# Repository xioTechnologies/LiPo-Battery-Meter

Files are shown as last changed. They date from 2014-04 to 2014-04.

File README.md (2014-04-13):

LiPo-Battery-Meter
==================

Battery meter for single cell [LiPo batteries](https://www.sparkfun.com/products/339) to display a battery voltage between 2.8 V to 4.2 V as an LED bar graph.  Uses the [LM3914](https://www.sparkfun.com/products/12694).  The PCB has foot prints compatible with either ten 1206 LEDs or a [single LED bar graph package](https://www.sparkfun.com/products/9935).  Inspired by [Dave Jone's tutorial](http://www.eevblog.com/2011/09/29/eevblog-204-designing-a-li-ion-battery-gauge-with-the-lm3914/).

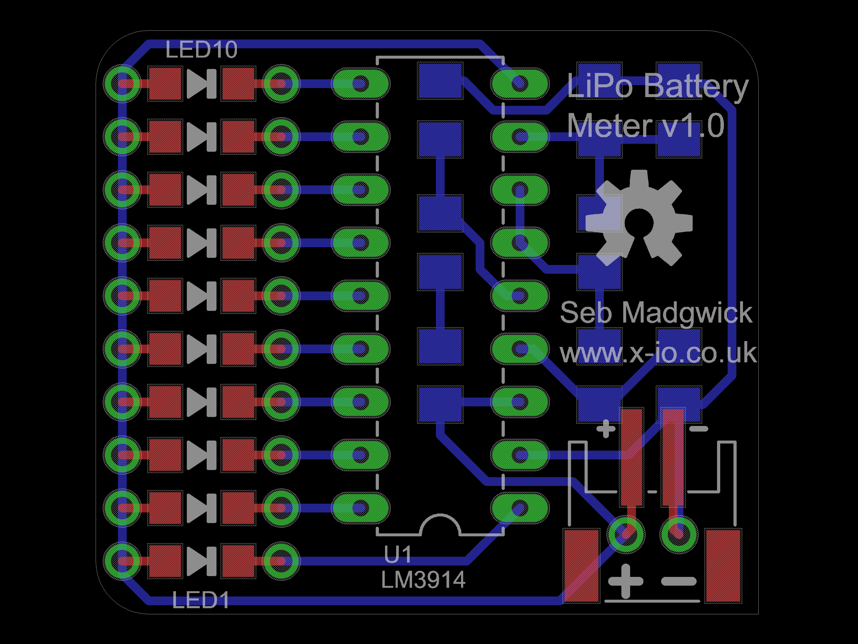
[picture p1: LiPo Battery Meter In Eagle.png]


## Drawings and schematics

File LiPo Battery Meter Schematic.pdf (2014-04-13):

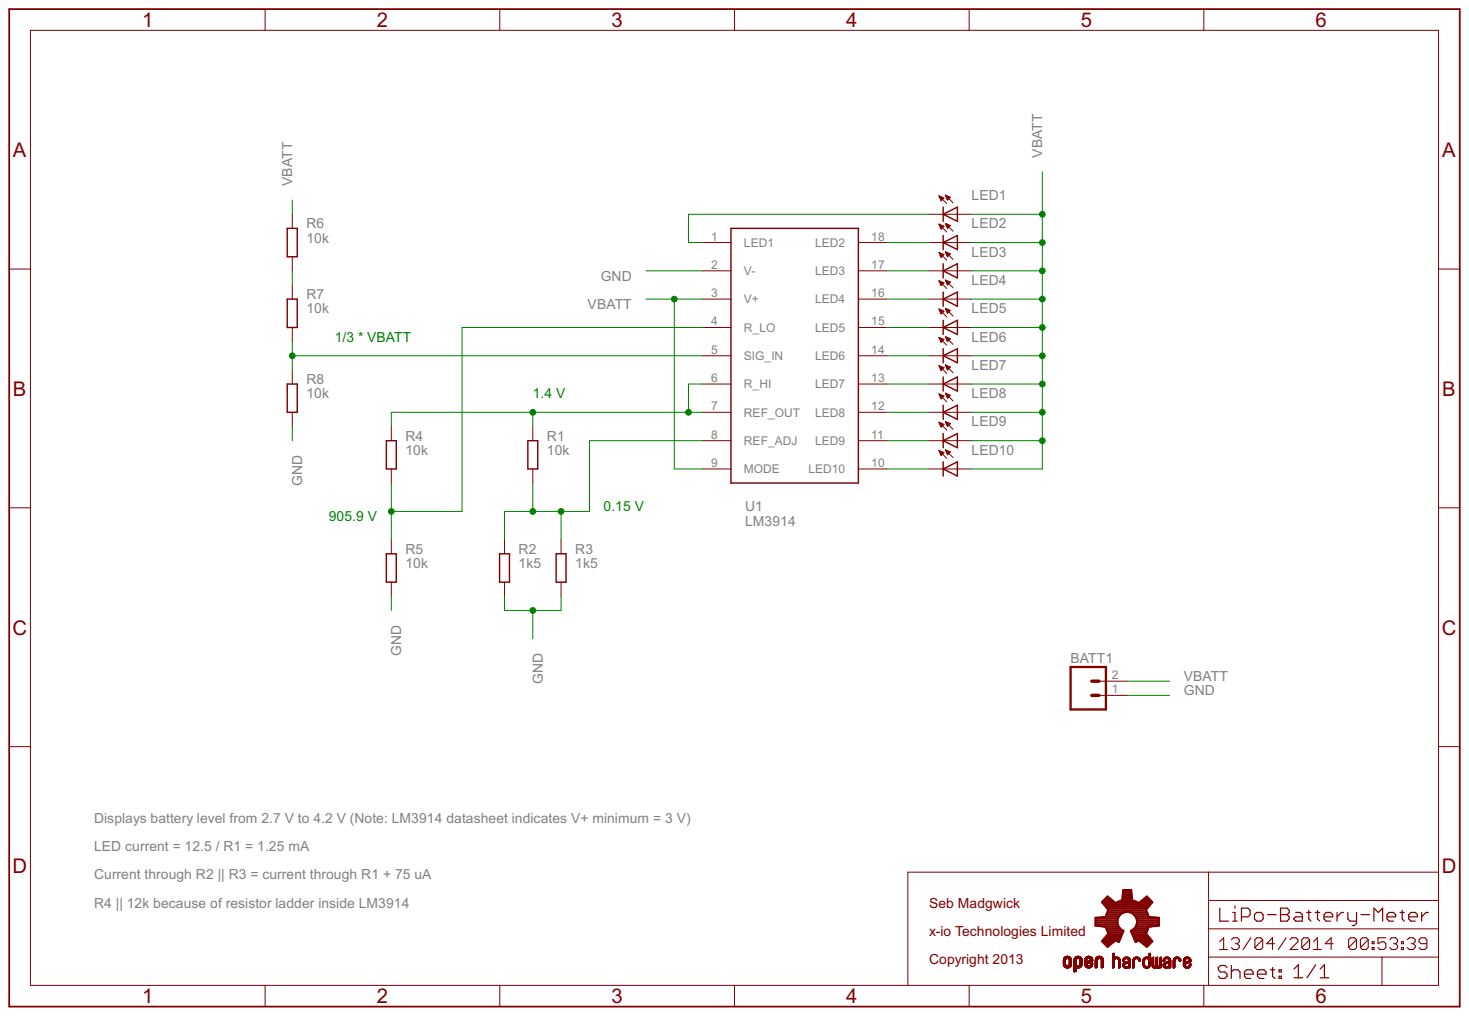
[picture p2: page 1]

5 | | LED6 14

1.4 V | | R_HI 6 | LED7 13

7 | | LED8 12

REF_ADJ 8 | LED9 11

9 | | LED10 10

Displays battery level from 2.7 V to 4.2 V (Note: LM3914 datasheet indicates V+ minimum = 3 V)

Current through R2 || R3 = current through R1 + 75 uA

R4 || 12k because of resistor ladder inside LM3914

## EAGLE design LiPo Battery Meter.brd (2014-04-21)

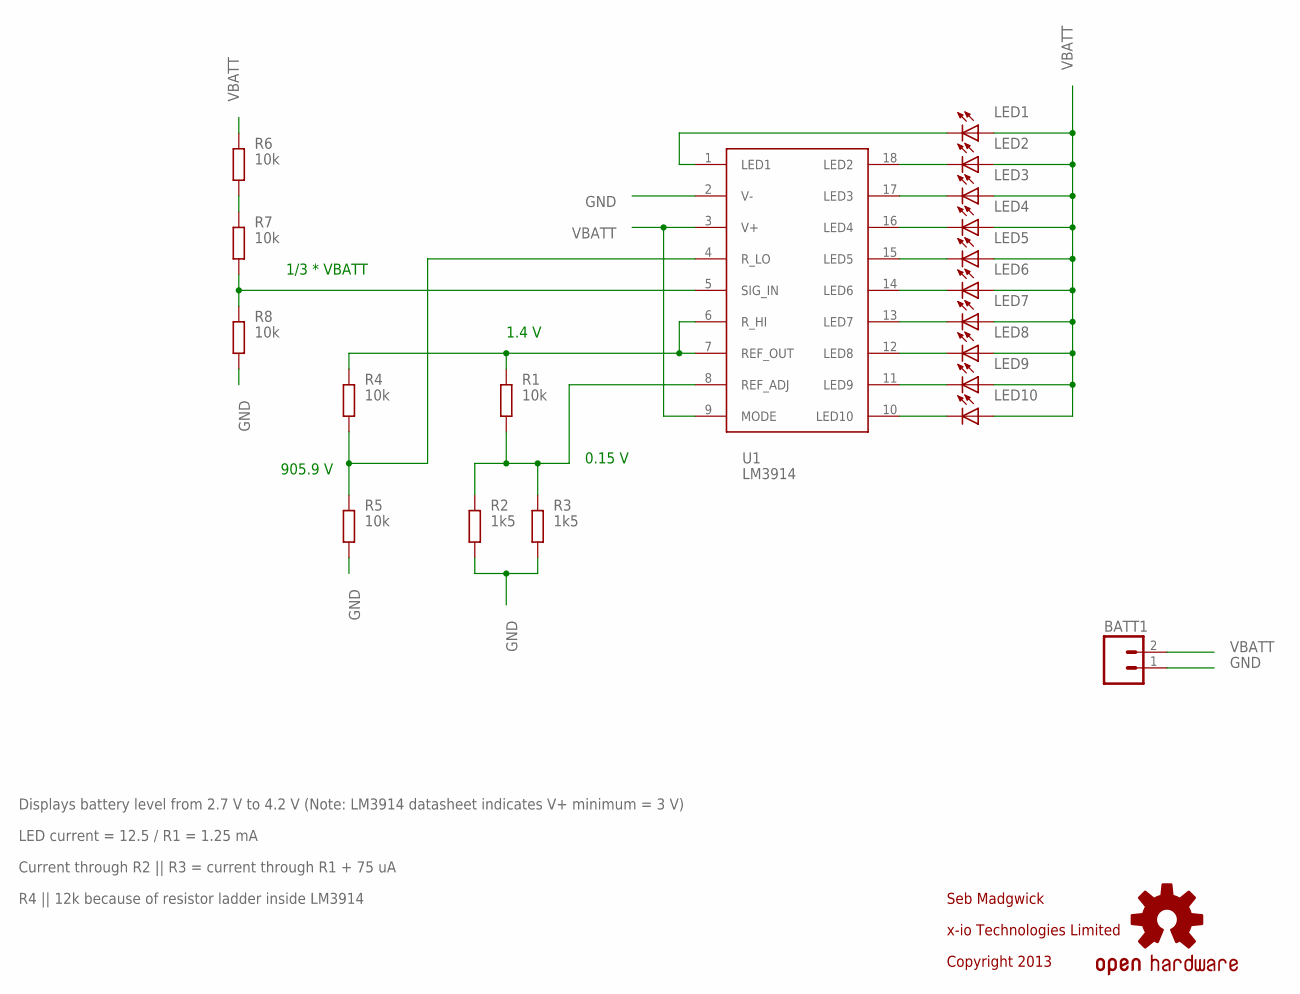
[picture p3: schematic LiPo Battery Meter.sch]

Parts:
BATT1: M02-JST-2MM-SMT; S2B-PH
LED1, LED2, LED3, LED4, LED5, LED6, LED7, LED8, LED9, LED10: LEDCHIPLED_1206; CHIPLED_1206
R1, R4, R5, R6, R7, R8: 10k; M1206
R2, R3: 1k5; M1206
U1: LM3914; DIL18
U$2: OSHW-LOGOM; OSHW-LOGO-M

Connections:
GND: BATT1.1, R2.1, R3.1, R5.1, R8.1, U1.2 (V-)
unnamed: R4.1, R5.2, U1.4 (R_LO)
unnamed: R7.1, R8.2, U1.5 (SIG_IN)
unnamed: R6.1, R7.2
unnamed: R1.1, R2.2, R3.2, U1.8 (REF_ADJ)
unnamed: LED10.C, U1.10 (LED10)
unnamed: LED9.C, U1.11 (LED9)
unnamed: LED8.C, U1.12 (LED8)
unnamed: LED7.C, U1.13 (LED7)
unnamed: LED6.C, U1.14 (LED6)
unnamed: LED5.C, U1.15 (LED5)
unnamed: LED4.C, U1.16 (LED4)
unnamed: LED3.C, U1.17 (LED3)
unnamed: LED2.C, U1.18 (LED2)
unnamed: LED1.C, U1.1 (LED1)
REF_OUT: R1.2, R4.2, U1.6 (R_HI), U1.7 (REF_OUT)
VBATT: BATT1.2, LED1.A, LED2.A, LED3.A, LED4.A, LED5.A, LED6.A, LED7.A, LED8.A, LED9.A, LED10.A, R6.2, U1.3 (V+), U1.9 (MODE)

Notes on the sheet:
Seb Madgwick
Copyright 2013
1.4 V
0.15 V
905.9 V
Displays battery level from 2.7 V to 4.2 V (Note: LM3914 datasheet indicates V+ minimum = 3 V)
1/3 * VBATT
Current through R2 || R3 = current through R1 + 75 uA
R4 || 12k because of resistor ladder inside LM3914
LED current = 12.5 / R1 = 1.25 mA
x-io Technologies Limited

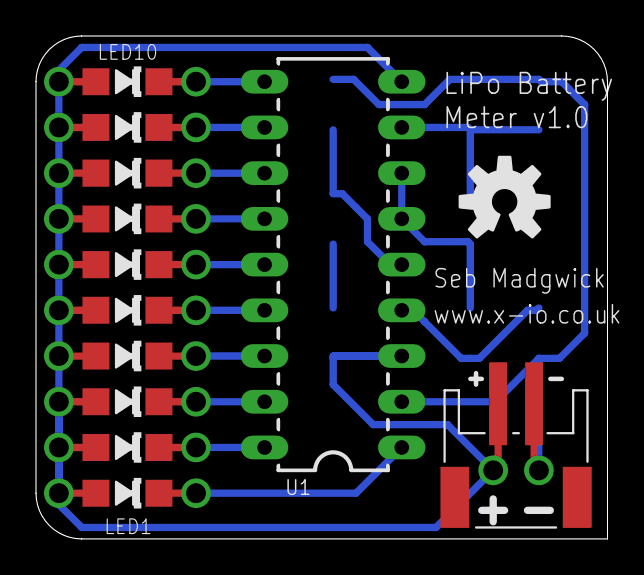
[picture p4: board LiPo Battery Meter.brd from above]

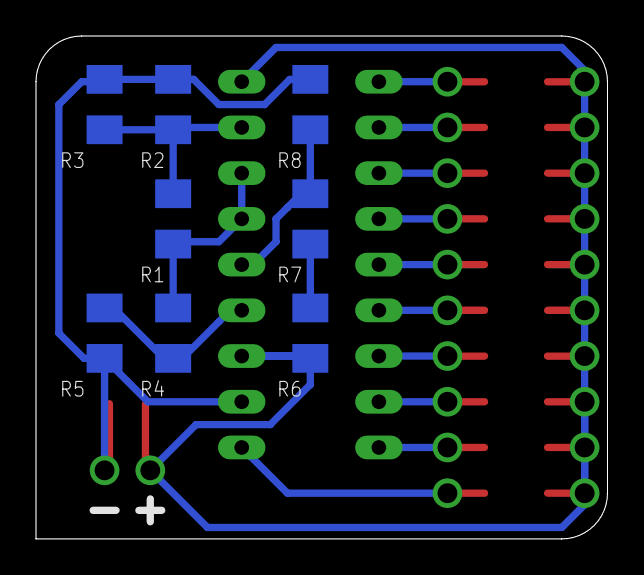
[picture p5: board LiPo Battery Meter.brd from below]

Board: 2 copper layers, 31.8 x 27.9 mm, 23 parts (8 on the bottom side), 17 nets.

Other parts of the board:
U$1: LIPO_BATTERY_METER_V1_0_BOTTOM
U$3: LIPO_BATTERY_METER_V1_0_TOP

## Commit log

2014-04-13 Add project files
    [LiPo-Battery-Meter.brd, LiPo-Battery-Meter.sch]
2014-04-13 Correct files names
    [LiPo Battery Meter.brd, LiPo Battery Meter.sch]
2014-04-13 Update image
    [LiPo Battery Meter.brd]
2014-04-21 Change silkscreen to 500 DPI
    [LiPo Battery Meter.brd]

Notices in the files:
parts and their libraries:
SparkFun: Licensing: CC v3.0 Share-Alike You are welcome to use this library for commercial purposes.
